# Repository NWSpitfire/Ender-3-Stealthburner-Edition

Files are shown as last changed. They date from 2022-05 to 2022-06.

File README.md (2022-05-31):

# Ender 3 Stealthburner Edition
 Voron Aesthetic/Hardware Mod for Original Ender3 V1. (WIP)

 This is an upgrade in Hardware, Electronics, Software and aesthetic for the Ender 3. It represents a massive increase in capability for your old Ender that will allow it to keep up with much more advanced (and expensive) 3D Printers.
 This mod is designed to be extremely cheap, utilising as much of the old system as possible.

 The main upgrades of this mod are;

 1: A switch from a Bowden fed PTFE Lined hotend system, to a direct drive all metal hotend using the Voron Stealthburner (Files not included, instead find them here; https://vorondesign.com/voron_stealthburner)

 2: The rewiring of the Power system to facilitate cleaner connections and easier integration with the raspberry Pi.

 3: The replacement of Marlin firmware with Klipper for both a performance and technical ability improvement.

 4: Replacement of the print bed surface with steel spring sheet for better adhesion and addition of very cheap auto levelling probe.

 Information;
 - This printer uses a Voron Stealthburner featuring an all metal E3D V6 hotend (with a 40W Heater cartridge) for printing up to 300C.
 - The bed is a Steel Spring textured PEI surface which can be used with most plastics with no need for any adhesive or layer agent.
 - The Klipper host used is a Raspberry Pi. This machine is running a Raspberry Pi 2, although can use a RPI 3, 4 or Zero 2.
 - The MCU is an upgraded Creality 4.2.7 32 bit mainboard, although in theory this should work with an original Creality 1.x.x board.
 - The power supply has been replaced (my original failed), but it is still running its original 24V 350W PSU (Non Meanwell).
 - The touch probe being used is based on Klicky, called the KlackEnder. Link to the files can be found here (Note, all KlackEnder Parts should be printed in ABS to ensure heat tolerance at higher temperatures); https://github.com/kevinakasam/KlackEnder-Probe
 - Environment temperature sensor used is a BMP280, which connects to the RPI and integrates with Klipper over I2C Bus.
 - Relay is used to control electronics cooling fans, with additional relay channels being added for extra features in time.

This documentation is a Work In Progress and will be updated over time, however the 3D Printer is fully functional and works correctly at this point.

BOM:

- E3D V6 (Cheaper to build from Spares): TBA
- Textured PEI Magnetic bed: TBA
- Raspberry Pi: TBA
- TBC

- CAD Model status: Incomplete - use at your own risk.
- Printer Status: Beta.

Credit for 3rd Party files used;

- Stealthburner (Missing from CAD Model) - Voron Design
- KlackEnder (Missing from CAD Model) - kevinakasam
- Creality MCU Board mount (Not used in CAD model but required - CAD Model Board mount deprecated) - DemoSTH (https://www.teamfdm.com/files/file/170-ender-3pro-switchwire/)

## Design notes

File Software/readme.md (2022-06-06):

This software is provided as a guide ONLY! 

USE AT YOUR OWN RISK!

It should be a good reference for pins, setup and offsets for the Creality 4.2.7 mainboard and stealthburner head. 

Used with Klipper and Mainsail.

Update 1.0.

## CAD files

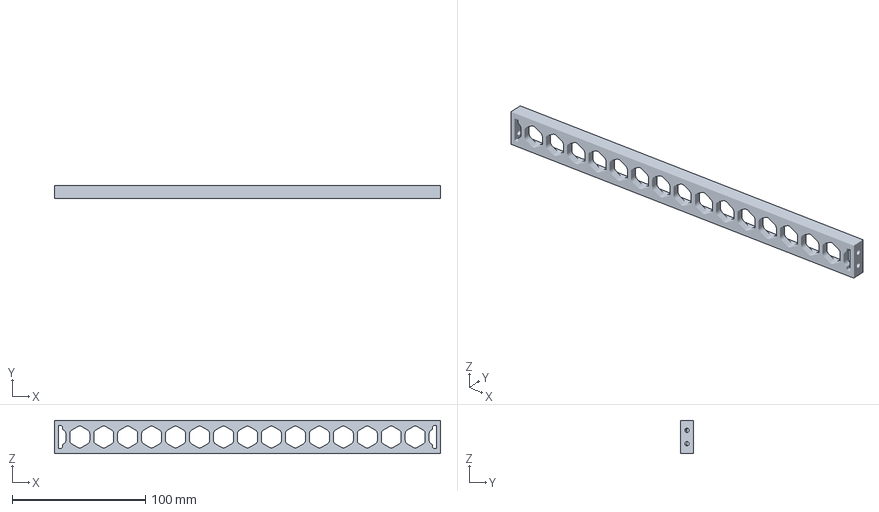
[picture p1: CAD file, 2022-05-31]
Build Files/Print3D/Side Grill/Side Grill Full.3MF
290.0 x 10.0 x 25.0 mm

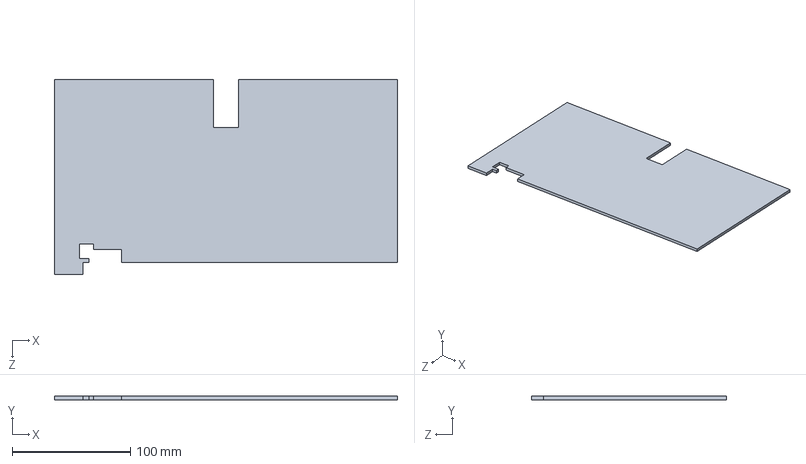
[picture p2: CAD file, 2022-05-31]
Build Files/Acrylic Deck/Acrylic Top Sheet Right back.SLDPRT
290.0 x 3.00 x 164.9 mm

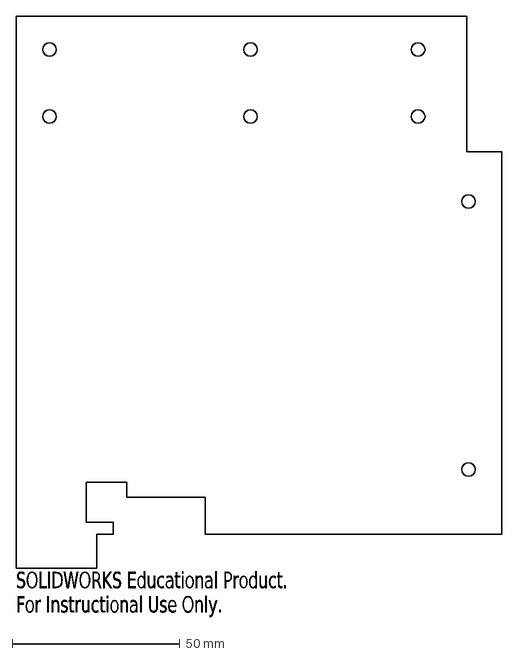
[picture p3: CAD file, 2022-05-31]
Build Files/Acrylic Deck/dxf/Acrylic Top Sheet Right.DXF
SOLIDWORKS Educational Product.
For Instructional Use Only.

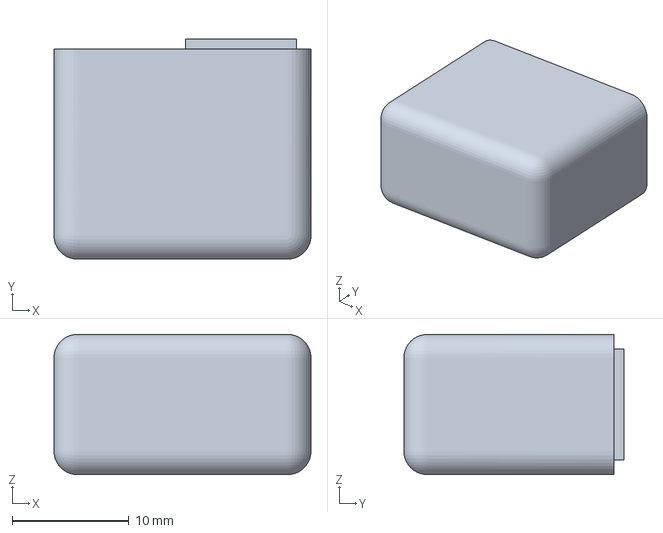
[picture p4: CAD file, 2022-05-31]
Build Files/Print3D/feet 18mm.3MF
22.0 x 18.9 x 12.0 mm

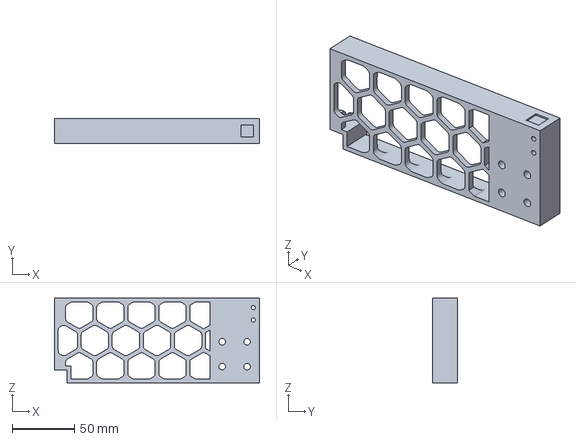
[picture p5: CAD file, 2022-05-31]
Build Files/Print3D/Front Grill/front Grill Right.3MF
164.9 x 20.0 x 68.0 mm

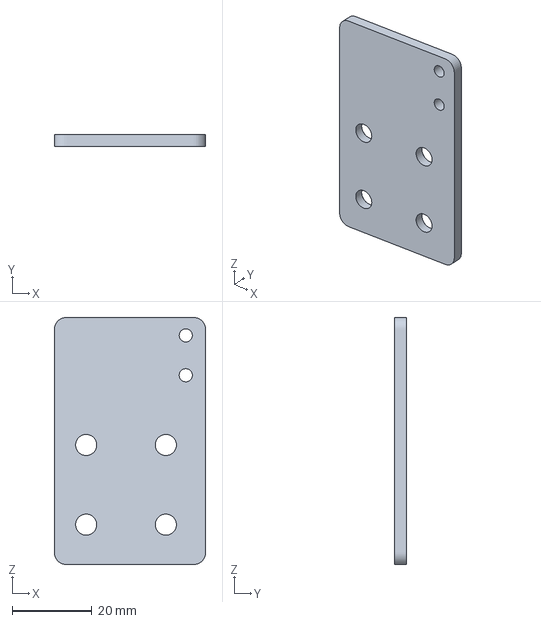
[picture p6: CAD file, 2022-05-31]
Build Files/Print3D/Logo Fascia Plate/Fascia Plate Logo v1.3MF
38.0 x 3.00 x 62.0 mm

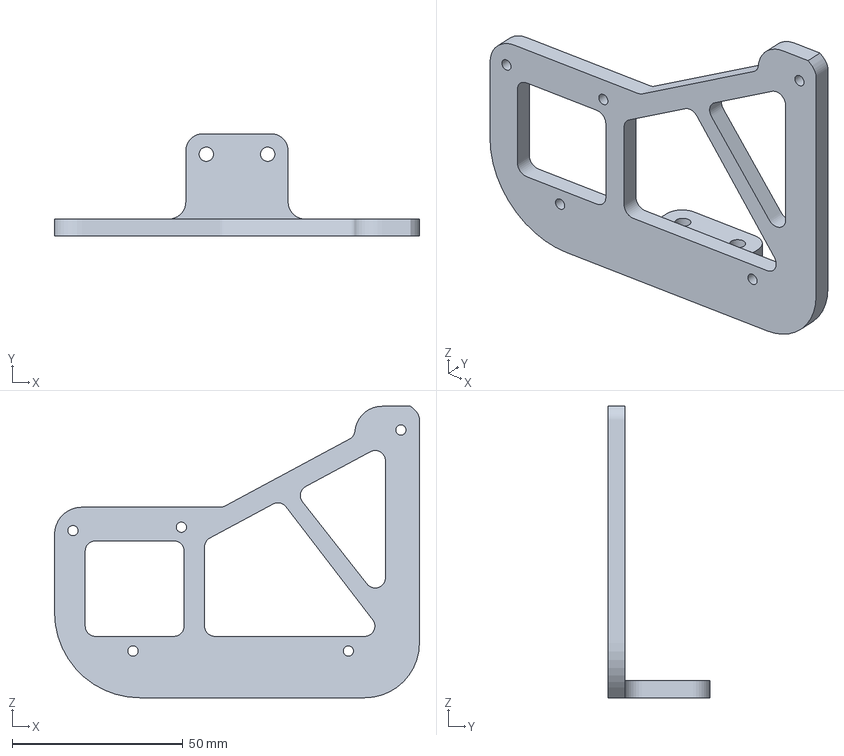
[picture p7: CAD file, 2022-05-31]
Build Files/Print3D/MCU Holder/MCU Holder.3MF
107.0 x 30.0 x 85.5 mm

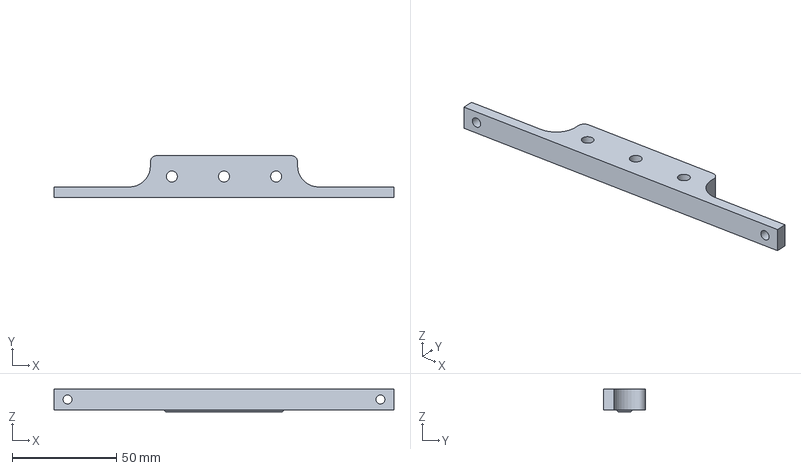
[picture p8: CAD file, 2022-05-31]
Build Files/Print3D/PSU Mount/PSU Mount.3MF
163.0 x 20.0 x 11.0 mm

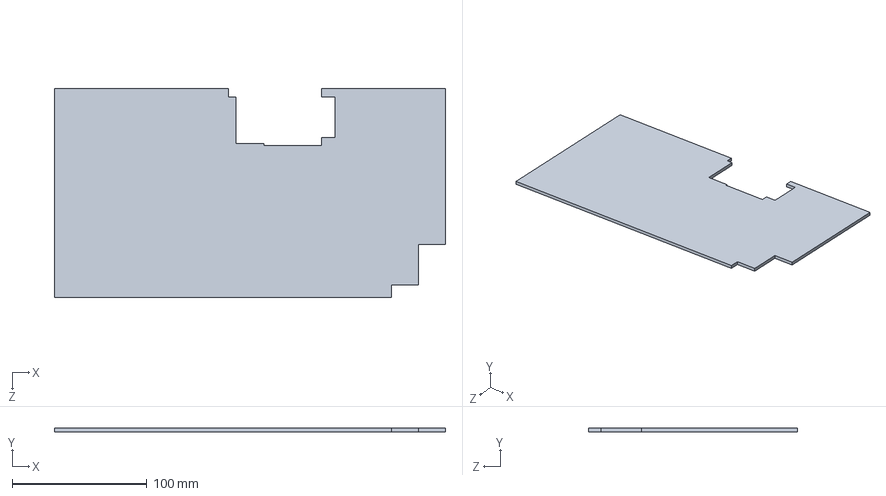
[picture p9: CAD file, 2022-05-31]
Build Files/Acrylic Deck/Acrylic Top Sheet Left Back.SLDPRT
290.0 x 3.00 x 154.7 mm

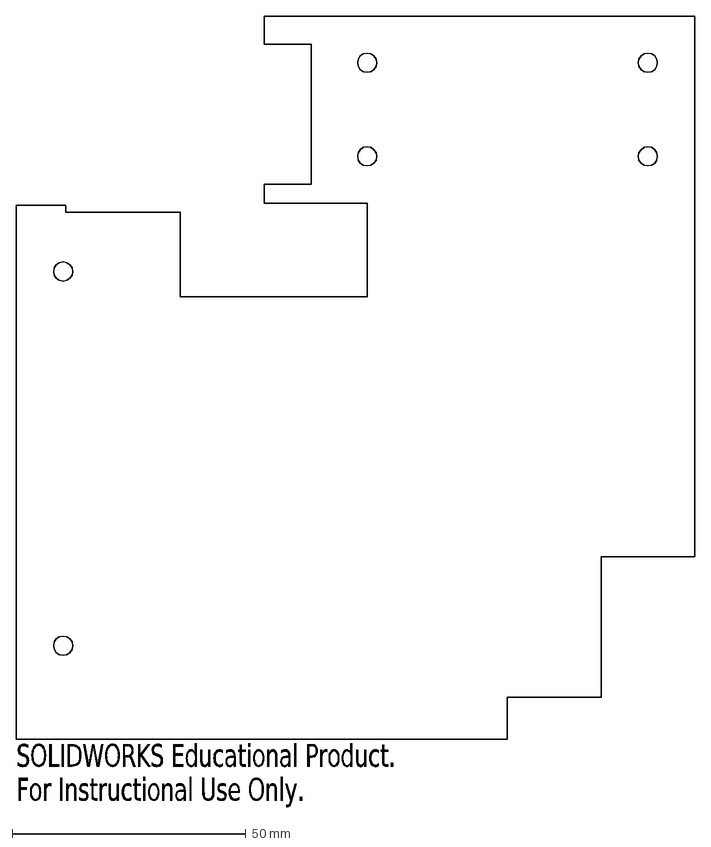
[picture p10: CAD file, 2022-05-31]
Build Files/Acrylic Deck/dxf/Acrylic Top Sheet Left.DXF
SOLIDWORKS Educational Product.
For Instructional Use Only.

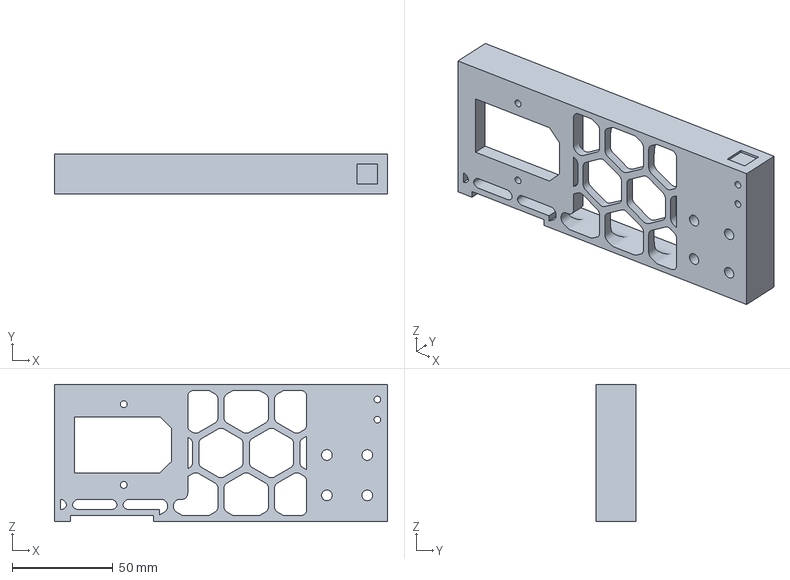
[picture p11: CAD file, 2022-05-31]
Build Files/Print3D/Rear Grill/rear Grill Right (IEC 320 Socket).3MF
164.9 x 20.0 x 68.0 mm

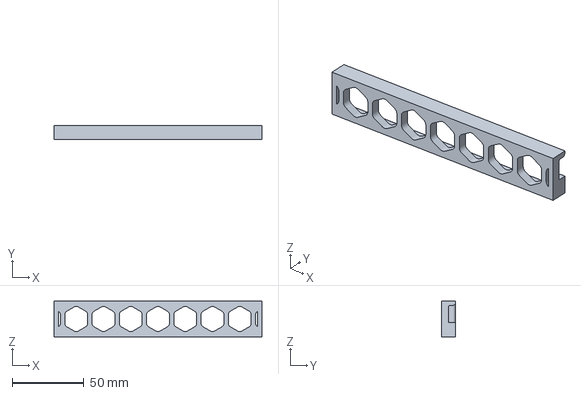
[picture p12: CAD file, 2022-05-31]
Build Files/Print3D/Side Grill/Side Grill Part 1.3MF
145.0 x 10.0 x 25.0 mm

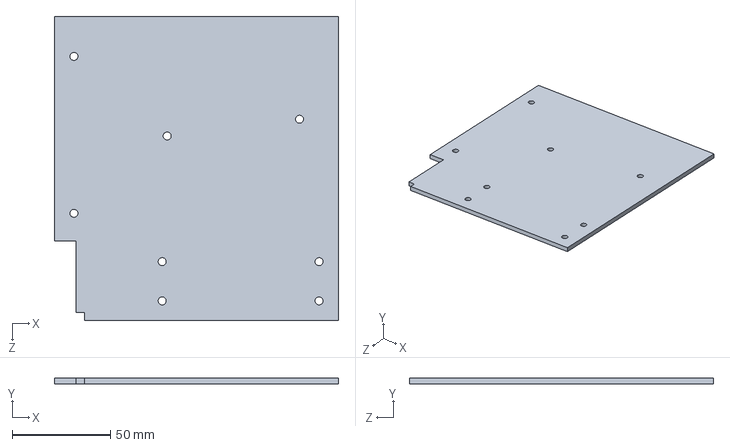
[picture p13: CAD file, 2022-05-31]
Build Files/Acrylic Deck/Acrylic Top Sheet Left front.SLDPRT
145.0 x 3.00 x 155.0 mm

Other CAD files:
Build Files/Print3D/Rear Grill/rear Grill Left (6020 Fan).3MF
Build Files/Print3D/Front Grill/front Grill Left.3MF
Build Files/Acrylic Deck/Acrylic Top Sheet Right front.SLDPRT
Build Files/Acrylic Deck/dxf/Acrylic Top Sheet Left front.DXF
Build Files/Acrylic Deck/dxf/Acrylic Top Sheet Right front.DXF

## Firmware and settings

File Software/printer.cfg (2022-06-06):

# This file contains pin mappings for the Creality "v4.2.7" board. To
# use this config, during "make menuconfig" select the STM32F103 with
# a "28KiB bootloader" and serial (on USART1 PA10/PA9) communication.

# If you prefer a direct serial connection, in "make menuconfig"
# select "Enable extra low-level configuration options" and select
# serial (on USART3 PB11/PB10), which is broken out on the 10 pin IDC
# cable used for the LCD module as follows:
# 3: Tx, 4: Rx, 9: GND, 10: VCC

# Flash this firmware by copying "out/klipper.bin" to a SD card and
# turning on the printer with the card inserted. The firmware
# filename must end in ".bin" and must not match the last filename
# that was flashed.

# See docs/Config_Reference.md for a description of parameters.

[stepper_x]
step_pin: PB9
dir_pin: PC2
enable_pin: !PC3
microsteps: 16
rotation_distance: 40
endstop_pin: ^PA5
position_endstop: 0
position_max: 250
homing_speed: 30

[stepper_y]
step_pin: PB7
dir_pin: PB8
enable_pin: !PC3
microsteps: 16
rotation_distance: 40
endstop_pin: ^PA6
position_endstop: 0
position_max: 235
homing_speed: 30

[stepper_z]
step_pin: PB5
dir_pin: !PB6
enable_pin: !PC3
microsteps: 16
rotation_distance: 8
endstop_pin: ^PA7
position_endstop: -.45 # THIS IS Z OFFSET FOR PROBE
position_max: 220
position_min: -.5

[printer]
kinematics: cartesian
max_velocity: 150
max_accel: 750
max_z_velocity: 20
max_z_accel: 100

[idle_timeout]
#gcode:
#   A list of G-Code commands to execute on an idle timeout. See
#   docs/Command_Templates.md for G-Code format. The default is to run
#   "TURN_OFF_HEATERS" and "M84".
timeout: 900
#   Idle time (in seconds) to wait before running the above G-Code
#   commands. The default is 600 seconds.


[fan]
pin: PA0

[mcu]
serial: /dev/serial/by-id/usb-1a86_USB_Serial-if00-port0
restart_method: command

[include display.cfg]

[include aliases.cfg]

[include sensors.cfg]

[include critical-macros.cfg]

[include other-macros.cfg]

[include heaters.cfg]

[include Input-Shaper.cfg]

[include relays.cfg]

#[include filament-sensor.cfg]

[include klicky.cfg]

#[include stealthburner_leds.cfg]

#*# <---------------------- SAVE_CONFIG ---------------------->
#*# DO NOT EDIT THIS BLOCK OR BELOW. The contents are auto-generated.
#*#
#*# [extruder]
#*# control = pid
#*# pid_kp = 18.160
#*# pid_ki = 0.859
#*# pid_kd = 96.019
#*#
#*# [heater_bed]
#*# control = pid
#*# pid_kp = 74.431
#*# pid_ki = 1.785
#*# pid_kd = 775.941
#*#
#*# [bed_mesh default]
#*# version = 1
#*# points =
#*# 	  0.035833, 0.054167, 0.015000, -0.008333, -0.083333
#*# 	  0.039167, 0.055000, 0.020000, -0.014167, -0.097500
#*# 	  0.070000, 0.007500, 0.000000, -0.060833, -0.144167
#*# 	  0.050000, 0.045000, 0.021667, -0.009167, -0.106667
#*# 	  0.145833, 0.095833, 0.080833, 0.060000, 0.014167
#*# tension = 0.2
#*# min_x = 30.0
#*# algo = bicubic
#*# y_count = 5
#*# mesh_y_pps = 4
#*# min_y = 35.0
#*# x_count = 5
#*# max_y = 221.0
#*# mesh_x_pps = 4
#*# max_x = 220.0

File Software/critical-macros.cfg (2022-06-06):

#All the required Critical Macros for Klipper/Printer Operation

[gcode_macro START_PRINT]
variable_bed_temp: 60
variable_extruder_temp: 185
gcode:
    # Start bed heating
    M140 S{bed_temp}
    #Preheat Nozzle
    #M109 S100
    # Use absolute coordinates
    G90
    # Reset the G-Code Z offset (adjust Z offset if needed)
    SET_GCODE_OFFSET Z=0
    # Home the printer
    G28
    #Raise to Z50
    G0 Z50
    # Wait for bed to reach temperature
    M190 S{bed_temp}
    #Run Bed Mesh
    AUTO_BED_MESH
    # Move the nozzle away from bed
    #G1 Z10 
    # Move XY to 0,0 Position for Nozzle Heatup
    #G1 X0 Y0 F1500
    #Load Bed Mesh before Nozzle heatup & Printing comit
    BED_MESH_PROFILE LOAD=default
    # Set and wait for nozzle to reach temperature
    M109 S{extruder_temp}
    #Activate Electronics Bay Cooling Fans for Print Duration
    SET_PIN PIN=electronics_cooling_fans VALUE=1.00
    # Reset Extruder
    G92 E0
    # Set new XY Home Coordinates at Bed Corner
    G0 Z5 ;move Z to pre Home zero Height
    G0 Y20 ;move Y to 20
    G0 X16 ;move X to 16
    G92 X0 Y0 ; Set New XY position on corner of bed
    # Move Z Axis to start
    G1 Z2.0 F3000
    # Move to start position
    G1 X0.1 Y20 Z0.3 F5000.0
    # Draw the first line
    G1 X0.1 Y165.0 Z0.3 F1500.0 E15 
    # Move to side a little
    G1 X0.4 Y165.0 Z0.3 F1500.0 E15 
    # Draw the second line
    G1 X0.4 Y20 Z0.3 F1500.0 E30
    # Reset Extruder
    G92 E0
    # Move Z Axis up
    G1 Z2.0 F3000

[gcode_macro END_PRINT]
gcode:
    # Turn off bed, extruder, and fan
    M140 S0
    M104 S0
    M106 S0
    # Relative positionning
    G91
    # Retract and raise Z
    G1 Z0.2 E-2 F2400
    # Wipe out
    #G1 X5 Y5 F3000
    # Raise Z more and pull final retraction
    G1 Z10 E-4
    # Absolute positionning
    G90
    # Present print
    G1 X0 Y200
    # Disable steppers but Z
    M84 X Y E
    #Disable Electronics Bay Cooling Fans
    SET_PIN PIN=electronics_cooling_fans VALUE=0.00

[pause_resume]

[gcode_macro PAUSE]
description: Pause the actual running print
rename_existing: PAUSE_BASE
gcode:
  PAUSE_BASE
  _TOOLHEAD_PARK_PAUSE_CANCEL

[gcode_macro RESUME]
description: Resume the actual running print
rename_existing: RESUME_BASE
gcode:
  ##### read extrude from  _TOOLHEAD_PARK_PAUSE_CANCEL  macro #####
  {% set extrude = printer['gcode_macro _TOOLHEAD_PARK_PAUSE_CANCEL'].extrude %}
  #### get VELOCITY parameter if specified ####
  {% if 'VELOCITY' in params|upper %}
    {% set get_params = ('VELOCITY=' + params.VELOCITY)  %}
  {%else %}
    {% set get_params = "" %}
  {% endif %}
  ##### end of definitions #####
  {% if printer.extruder.can_extrude|lower == 'true' %}
    M83
    G1 E{extrude} F2100
    {% if printer.gcode_move.absolute_extrude |lower == 'true' %} M82 {% endif %}
  {% else %}
    {action_respond_info("Extruder not hot enough")}
  {% endif %}  
  RESUME_BASE {get_params}

#[gcode_macro CANCEL_PRINT]
#description: Cancel the actual running print
#rename_existing: CANCEL_PRINT_BASE
#variable_park: True
#gcode:
#  ## Move head and retract only if not already in the pause state and park set to true
# {% if printer.pause_resume.is_paused|lower == 'false' and park|lower == 'true'%}
#    _TOOLHEAD_PARK_PAUSE_CANCEL
#  {% endif %}
#  TURN_OFF_HEATERS
#  CANCEL_PRINT_BASE

[gcode_macro CANCEL_PRINT]
description: Cancel the actual running print
rename_existing: CANCEL_PRINT_BASE
gcode:
      M220 S100 ;Reset Speed factor override percentage to default (100%)
      M221 S100 ;Reset Extrude factor override percentage to default (100%)
       # Turn off bed, extruder, and fan
      M140 S0
      M104 S0
      M106 S0
      # Relative positionning
      G91
      # Retract and raise Z
      G1 Z0.2 E-2 F2400
      # Wipe out
      #G1 X5 Y5 F3000
      # Raise Z more and pull final retraction
      G1 Z10 E-4
      # Absolute positionning
      G90
      # Present print
      G1 X0 Y200
      # Disable steppers
      M84 X Y E


[gcode_macro _TOOLHEAD_PARK_PAUSE_CANCEL]
description: Helper: park toolhead used in PAUSE and CANCEL_PRINT
variable_extrude: 1.0
gcode:
  ##### set park positon for x and y #####
  # default is your max posion from your printer.cfg
  {% set x_park = printer.toolhead.axis_maximum.x|float - 5.0 %}
  {% set y_park = printer.toolhead.axis_maximum.y|float - 5.0 %}
  {% set z_park_delta = 2.0 %}
  ##### calculate save lift position #####
  {% set max_z = printer.toolhead.axis_maximum.z|float %}
  {% set act_z = printer.toolhead.position.z|float %}
  {% if act_z < (max_z - z_park_delta) %}
    {% set z_safe = z_park_delta %}
  {% else %}
    {% set z_safe = max_z - act_z %}
  {% endif %}
  ##### end of definitions #####
  {% if printer.extruder.can_extrude|lower == 'true' %}
    M83
    G1 E-{extrude} F2100
    {% if printer.gcode_move.absolute_extrude |lower == 'true' %} M82 {% endif %}
  {% else %}
    {action_respond_info("Extruder not hot enough")}
  {% endif %}
  {% if "xyz" in printer.toolhead.homed_axes %}
    G91
    G1 Z{z_safe} F900
    G90
    G1 X{x_park} Y{y_park} F6000
    {% if printer.gcode_move.absolute_coordinates|lower == 'false' %} G91 {% endif %}
  {% else %}
    {action_respond_info("Printer not homed")}
  {% endif %}

[virtual_sdcard]
path: /home/pi/gcode_files

[display_status]

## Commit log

2022-05-31 Added Build Files
    These files contain STL's for 3D Printing and DXF For Laser cutting - Where required.
    [Acrylic Top Sheet Left Back.SLDPRT, Acrylic Top Sheet Left front.DXF, Acrylic Top Sheet Left front.SLDPRT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]
2022-06-06 Added KIipper software config files
    This is reference software config used on my machine.
    Update 1
    [Input-Shaper.cfg, aliases.cfg, critical-macros.cfg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]
